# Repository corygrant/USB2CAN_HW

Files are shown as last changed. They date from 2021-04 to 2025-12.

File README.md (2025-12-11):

# USB2CAN_HW
USB to CAN adapter based on the work done by [Hubert Denkmair](https://github.com/HubertD) and [Ethan Zonca](https://github.com/normaldotcom)

The project was started because of the shortage of STM32 parts available.

The STM32F072xB and STM32F042x6 were both unavailable with no time frame for availability.

The STM32F302C8 was chosen primarily because it was available, and because it included CAN/USB capabilities.

The USB2CAN board does not feature galvanic isolation.

The protocol implemented is SLCAN, although not all functions are complete or included. 

The firmware is a combination of [canable firmware](https://github.com/normaldotcom/canable-fw) and [candleLight firmware](https://github.com/candle-usb/candleLight_fw)

# [Store](https://dingo-electronics.square.site/product/usb2can/2)

# Photos

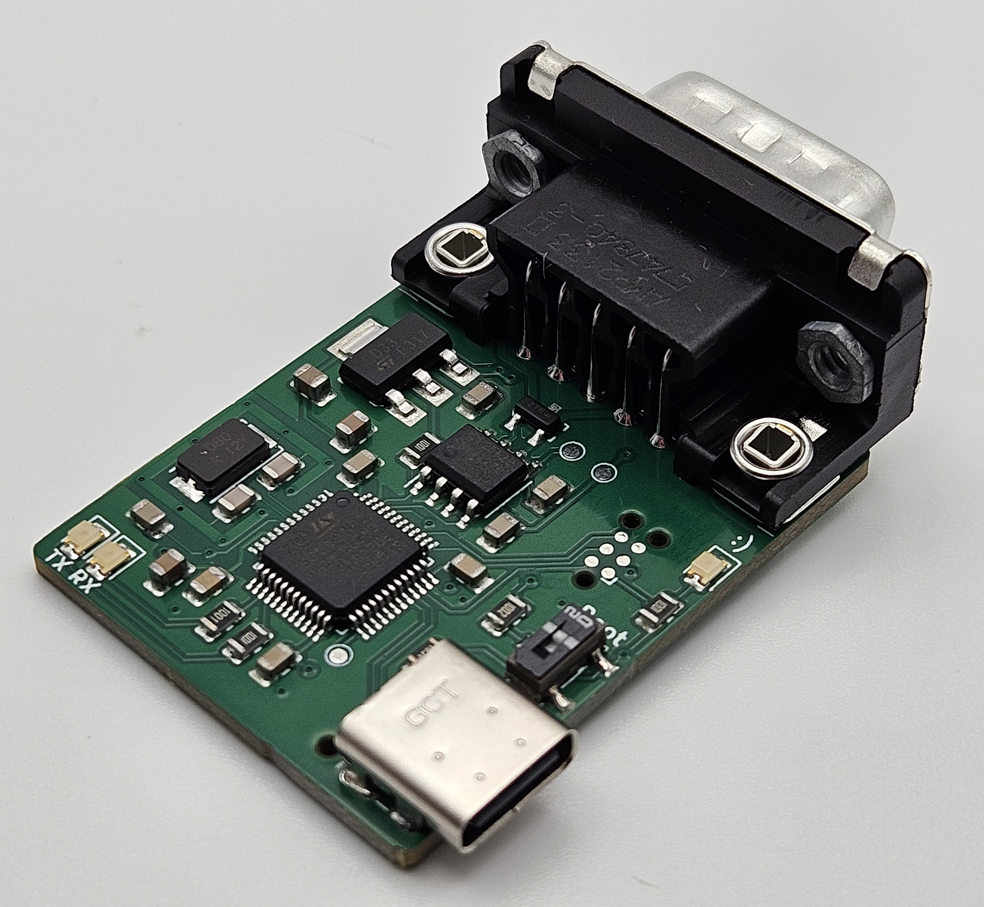
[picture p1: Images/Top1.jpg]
Top


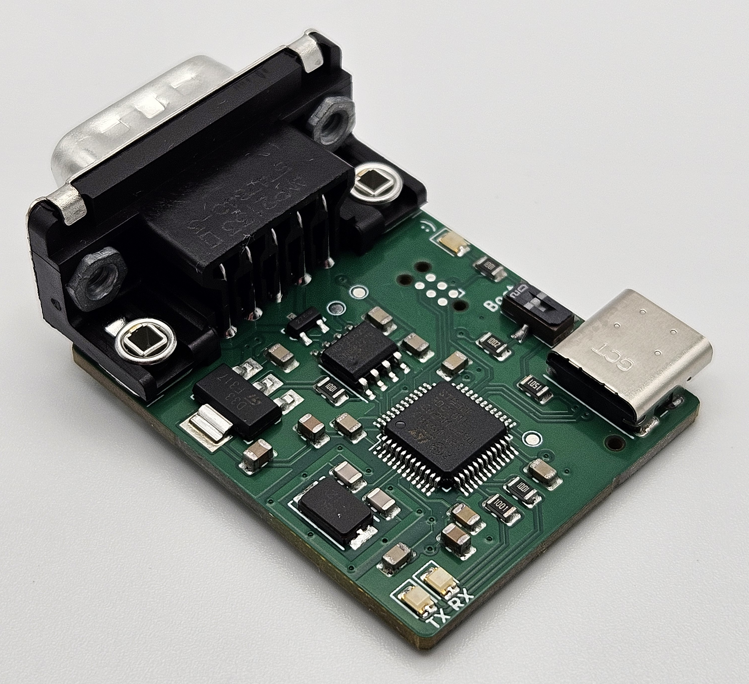
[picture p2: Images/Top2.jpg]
Top2


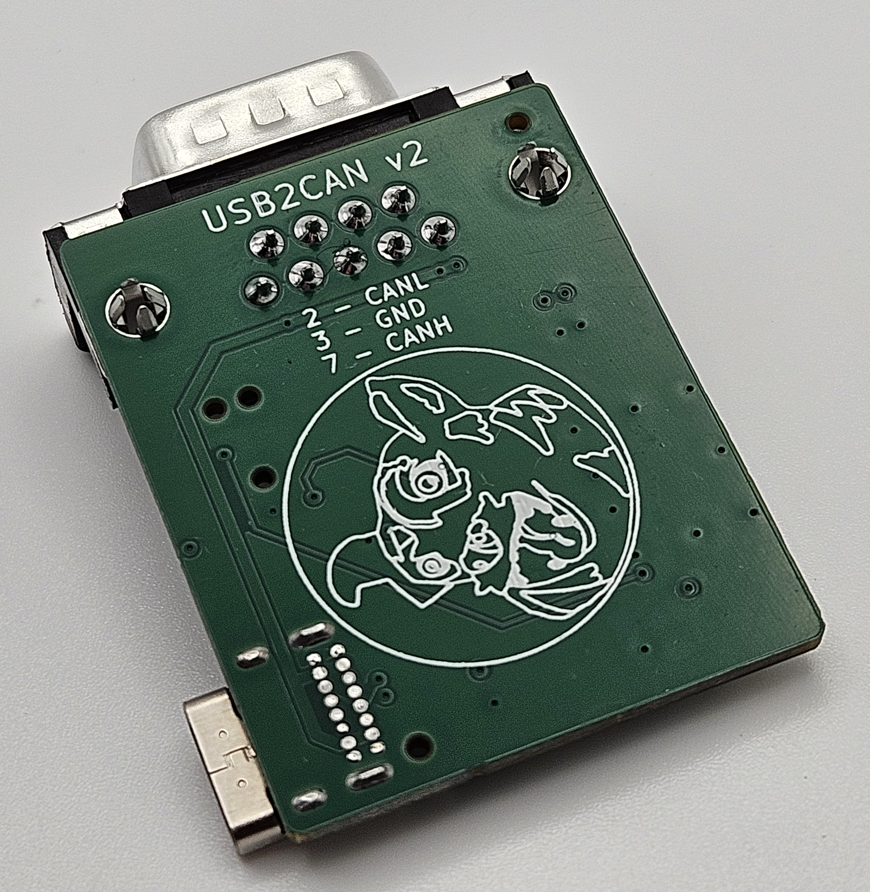
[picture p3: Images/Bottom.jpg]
Bottom


# Connection

| Pin | Function |
|-----|---|
| 1 | |
| 2 | CAN_L |
| 3 | GND |
| 4 | |
| 5 | |
| 6 | |
| 7 | CAN_H |
| 8 | |
| 9 | |

# BOM

[Interactive BOM](https://htmlpreview.github.io/?https://github.com/corygrant/USB2CAN_HW/blob/main/docs/bom/ibom.html)

# Firmware

[USB2CAN firmware](https://github.com/corygrant/USB2CAN_FW/releases)

# Firmware Update

Updating the USB2CAN firmware follows the same process as the dingoPDM. 

See the instructions here: [dingoPDM Firmware Update](https://corygrant.github.io/dingoPDM/firmware/updating/)

# Disclaimer

Please note that this product has been designed by a hobbyist, not a professional. It is intended for off-road and testing use only. Users should operate the product at their own discretion and risk. The designer explicitly disclaims any responsibility for damage or injury that may result from the use of this product.

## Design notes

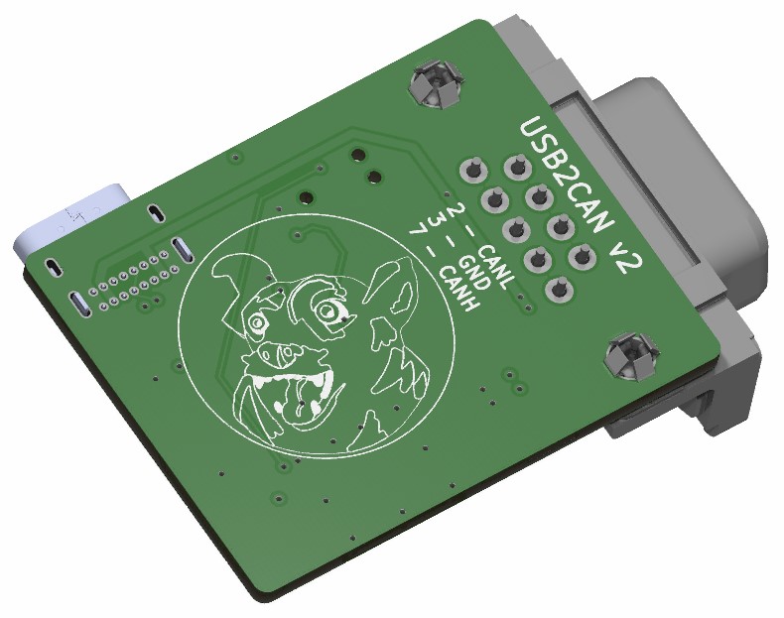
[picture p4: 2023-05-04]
Renders/USB2CAN_Bottom.jpg

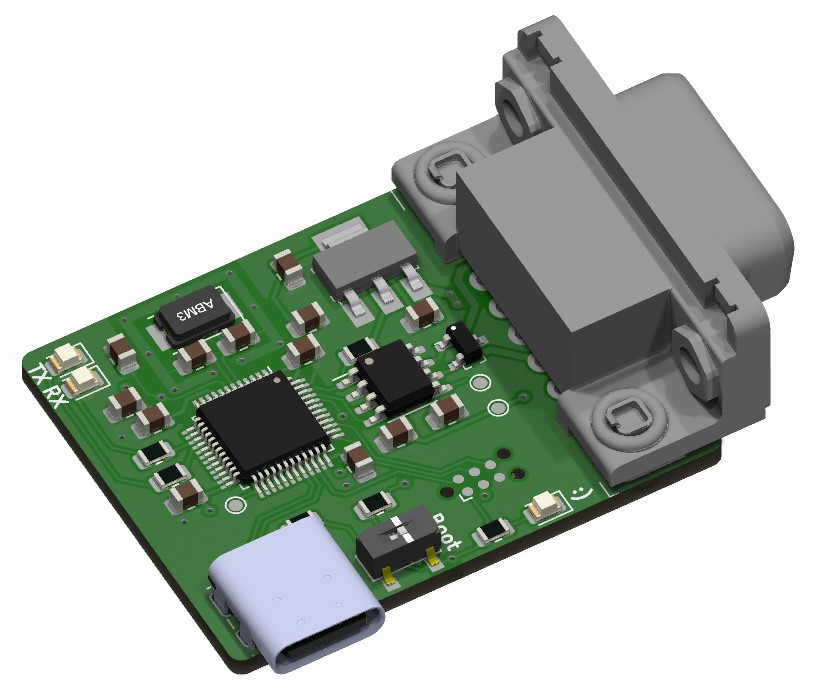
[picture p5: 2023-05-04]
Renders/USB2CAN_Top.jpg

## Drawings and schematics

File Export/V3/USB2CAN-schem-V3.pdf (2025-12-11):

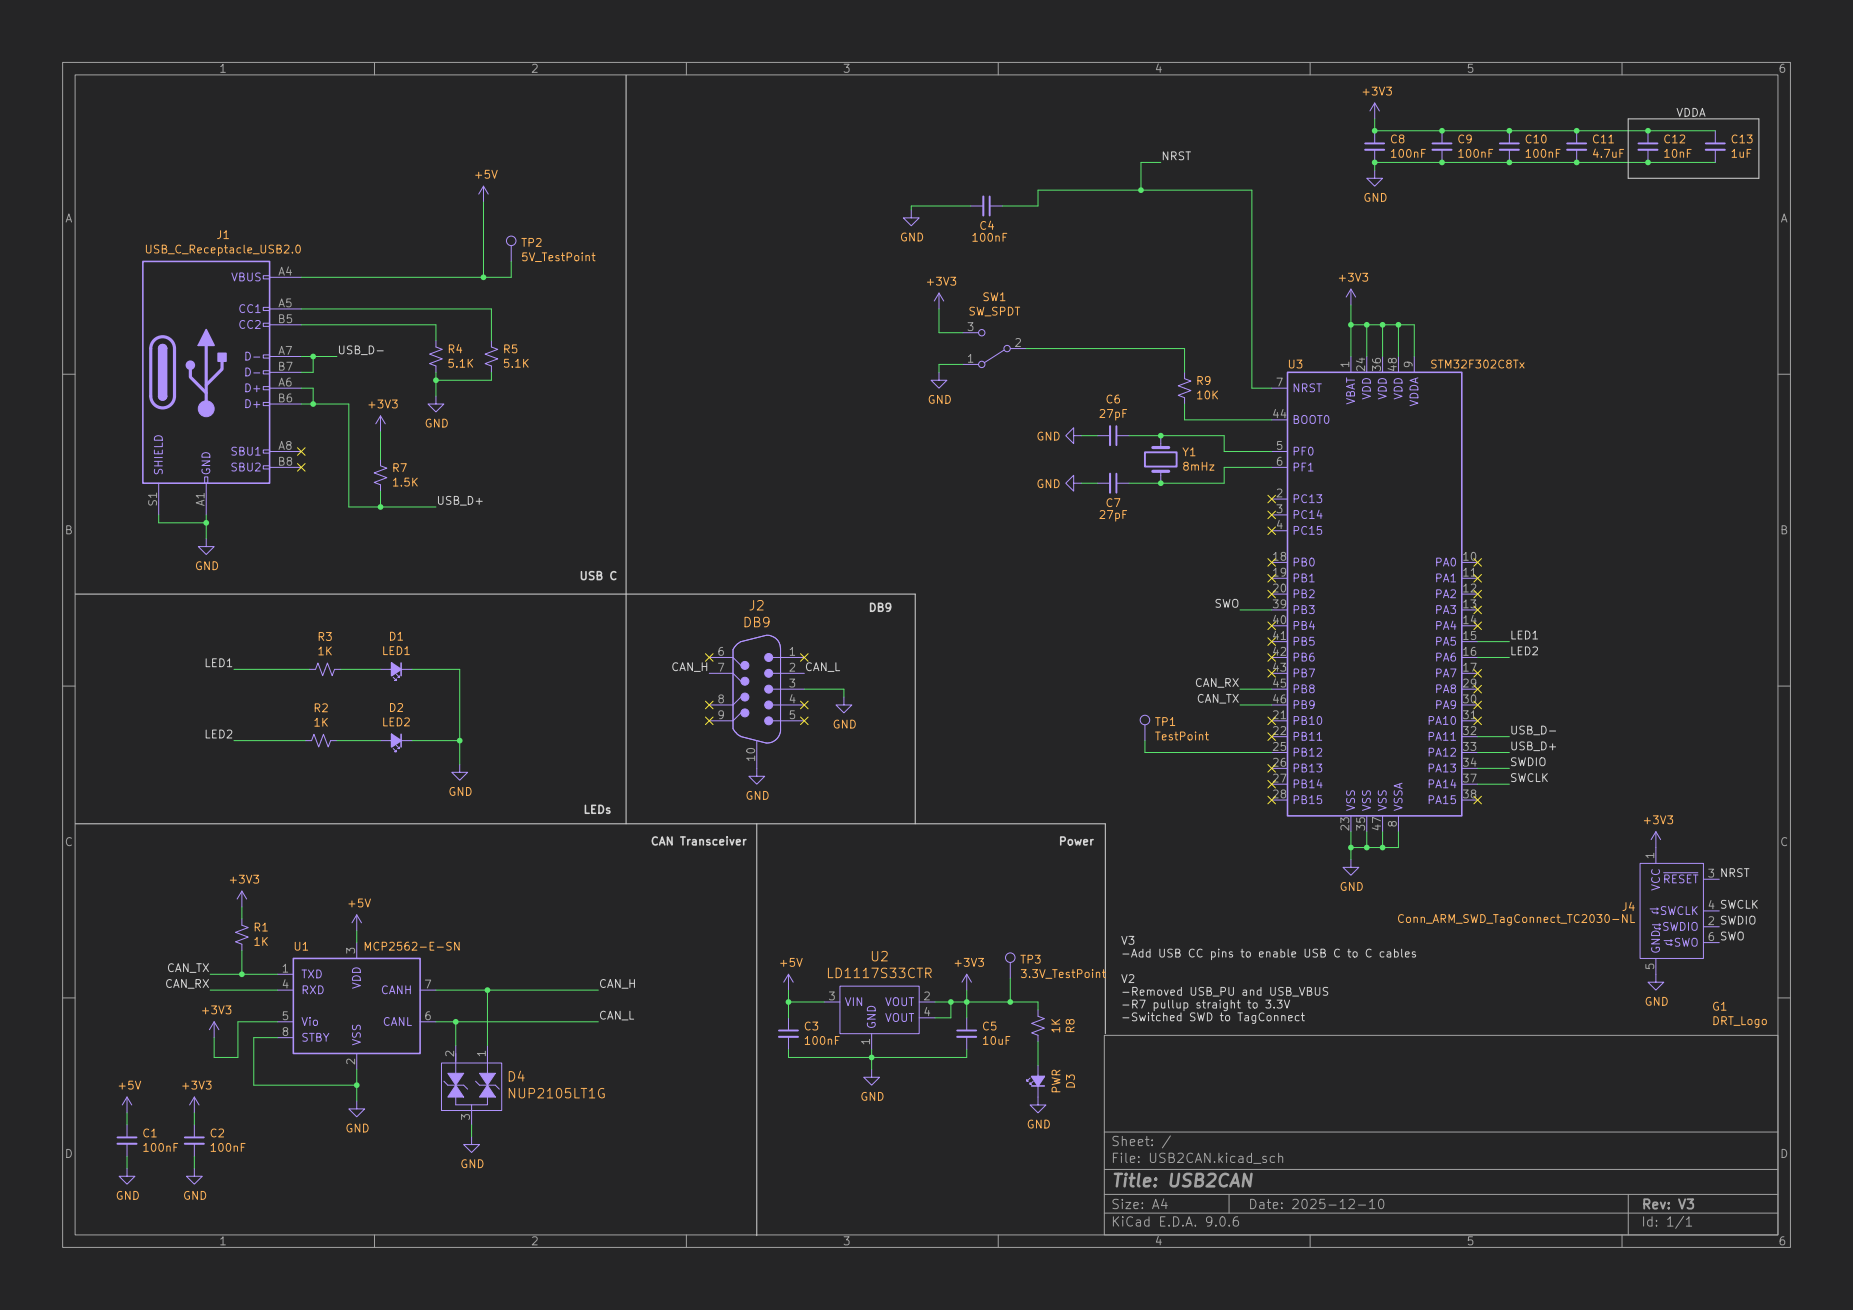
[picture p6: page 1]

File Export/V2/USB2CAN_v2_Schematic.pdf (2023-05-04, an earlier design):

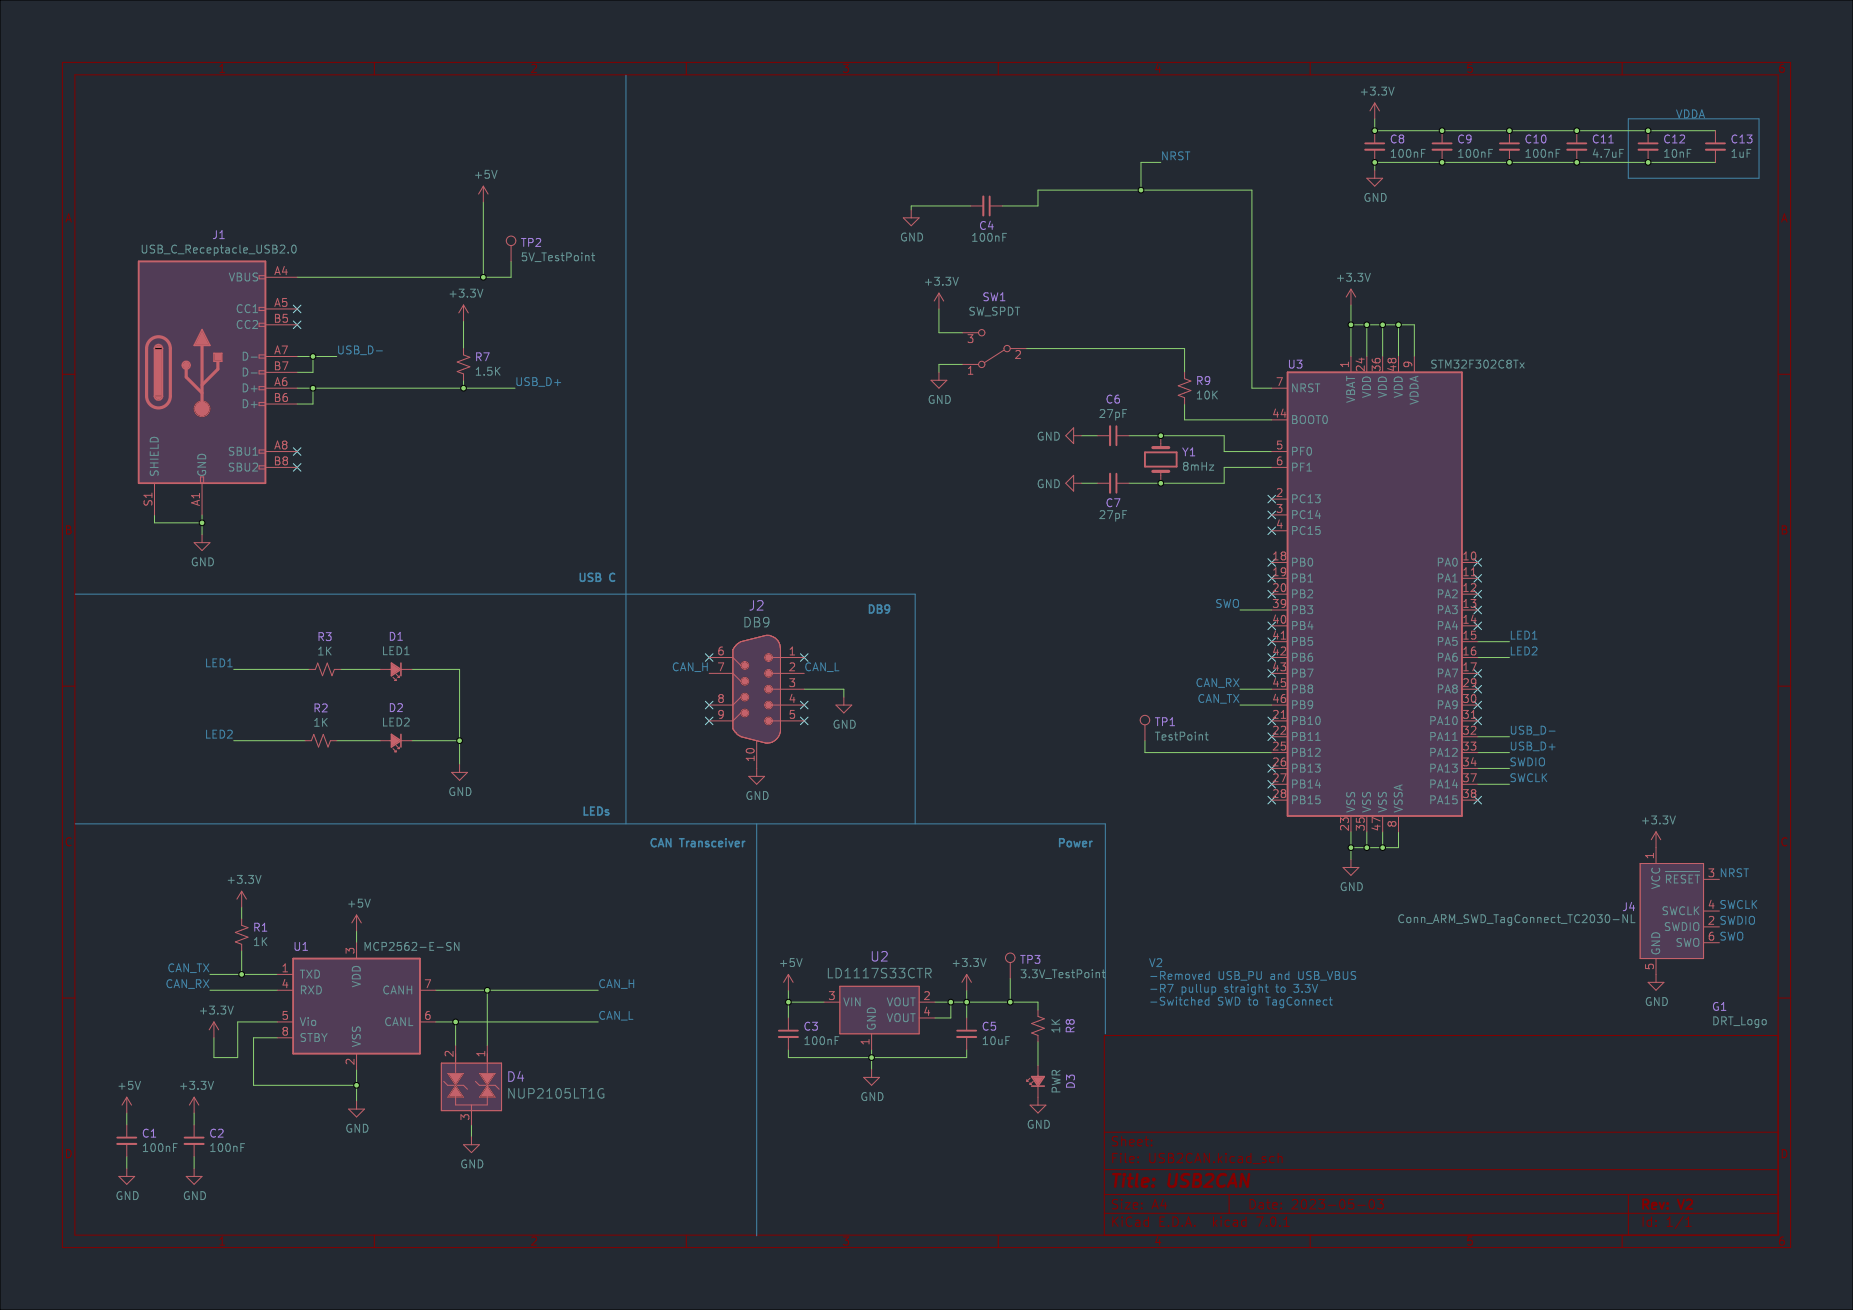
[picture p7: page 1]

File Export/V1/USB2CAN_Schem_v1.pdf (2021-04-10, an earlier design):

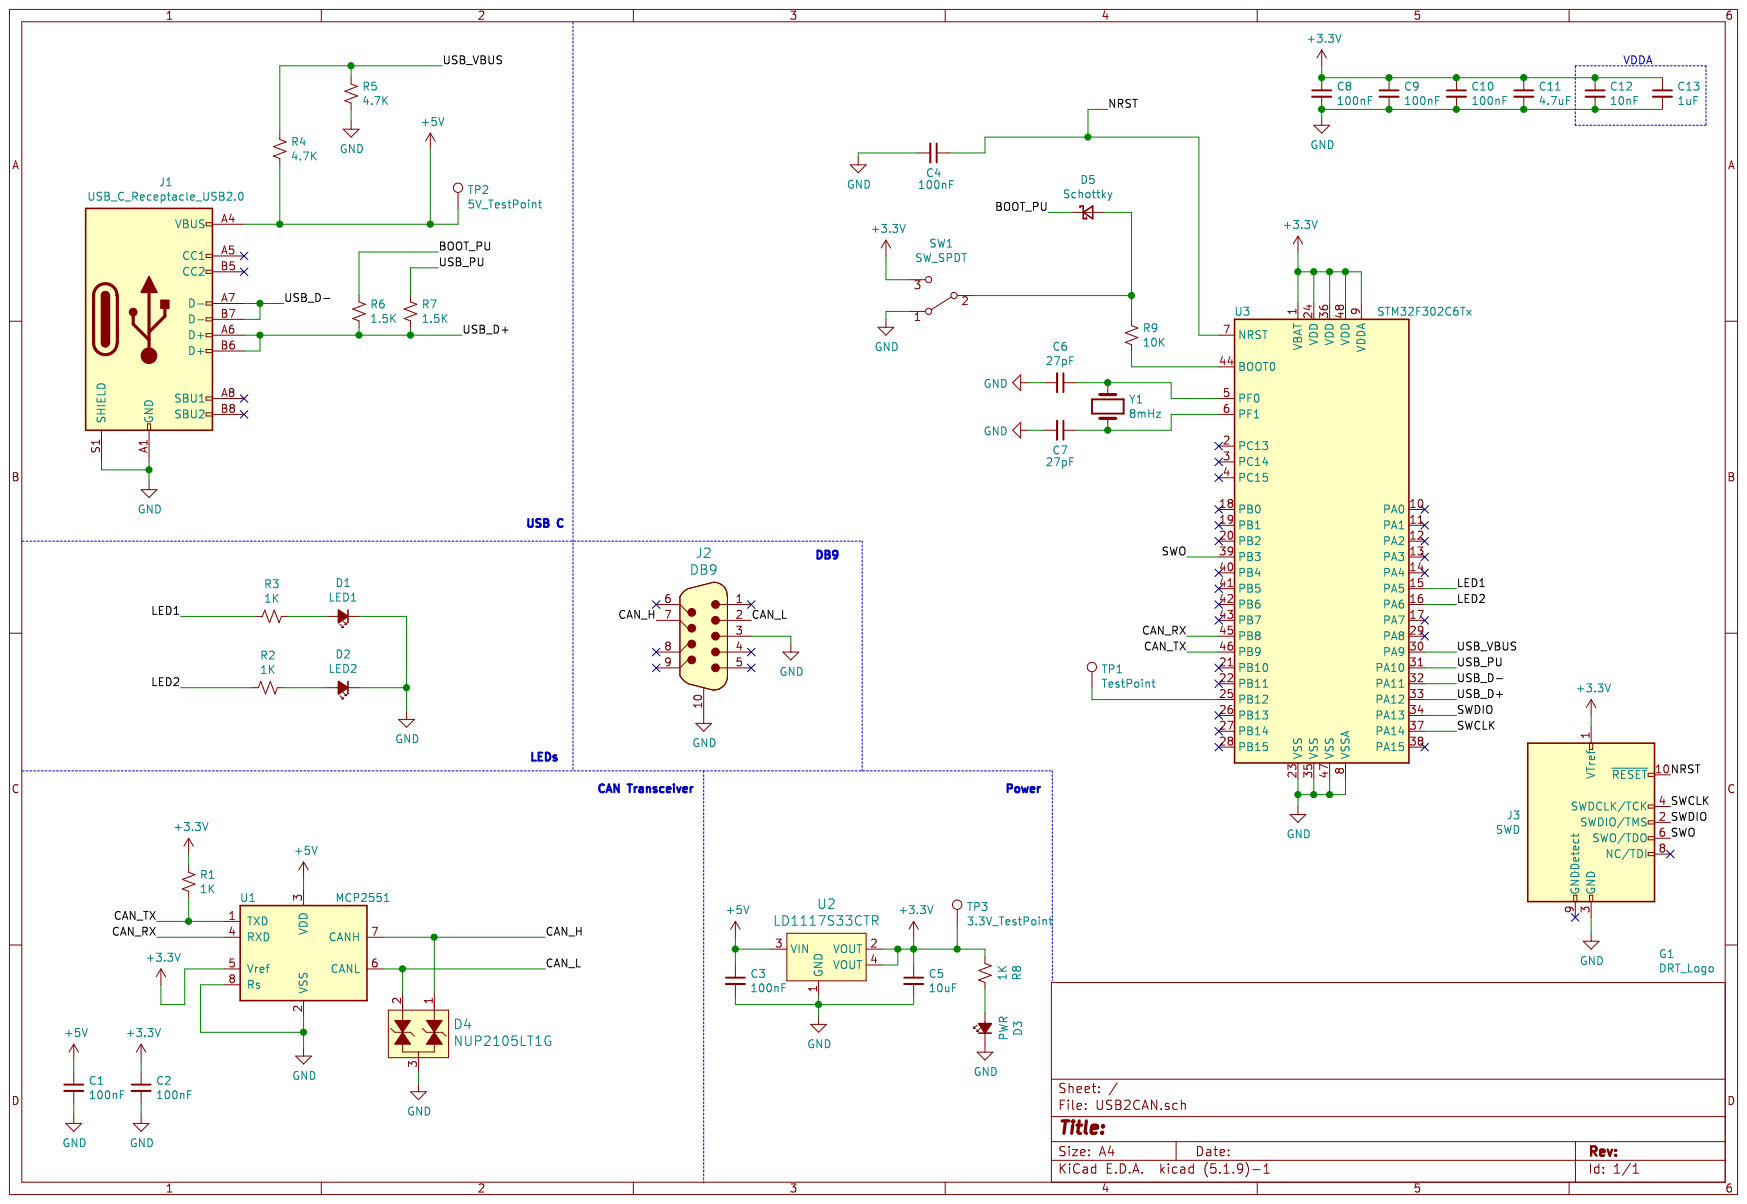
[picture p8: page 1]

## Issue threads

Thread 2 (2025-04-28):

Missing CC resistors

corygrant, 2025-04-28:
Will not work on a USB C port, must use USB A

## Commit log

2021-04-10 Reorganizing files
    [USB2CAN-B_Cu.gbl, USB2CAN-B_Mask.gbs, USB2CAN-B_Paste.gbp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]
2021-05-12 Swapped MCP2551 to MCP2562
    [USB2CAN.kicad_pcb, USB2CAN.sch]
2022-04-05 Removed USB_PU and USB_VBUS, R7 straight to 3.3V
    [USB2CAN.kicad_sch]
2022-10-15 Kicad V6 updates
    [USB2CAN.kicad_pcb, USB2CAN.kicad_sch]
2023-05-04 V2, as ordered
    Changed to TagConnect, fixed USB
    [USB2CAN-B_Cu.gbl, USB2CAN-B_Mask.gbs, USB2CAN-B_Paste.gbp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]
2024-09-06 Update to Kicad 8
    [USB2CAN.kicad_pcb, USB2CAN.kicad_sch]
2025-04-24 update to kicad 9.0.1
    [USB2CAN.kicad_pcb, USB2CAN.kicad_sch]
2025-08-19 move footprints to local library
    [USB2CAN.kicad_pcb, USB2CAN.kicad_sch]
2025-12-11 add cc resistors to usb c
    [USB2CAN.kicad_pcb, USB2CAN.kicad_sch]
2025-12-11 add v3 schem
    [USB2CAN.kicad_sch]
2025-12-11 Fix link to Interactive BOM in README
